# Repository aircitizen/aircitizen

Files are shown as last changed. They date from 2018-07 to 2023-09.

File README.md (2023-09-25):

# AirCitizen

## Air quality measured by citizens

This is the main repo of the [aircitizen](http://www.aircitizen.org) project. The aircitizen project is a citizen science project about air quality.

aircitizen station for CN2 workshops

We develop air quality measurement stations at [Fablab Sorbonne](https://fablab.sorbonne-universite.fr/) in Paris, France and organize participatory workshops (construction of the stations, measurements in a particular neighborhood, data visualization and discussion, ...) with citizens.

## Development

The project is currently under active development. Feel free to contact us if you want to join !

## License



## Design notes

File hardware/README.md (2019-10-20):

<!---just a comment --->

This is the hardware page of the [AirCitizen](http://www.aircitizen.org) project. 

#  Mobile station

We developped this station for the Cité des sciences et de l'industrie and the turfu workshops.

1. arduino mega board
2. battery
3. grove mega shield
4. grove GPS
5. grove temperature and humidity sensor (DHT22)
6. PM sensor Plantower PMS3003 (non grove) with 4-pin adaptor and grove cable
7. I2C OLED display
8. uSD card reader/writer (non grove) with 8Go SD card

<p align="center">
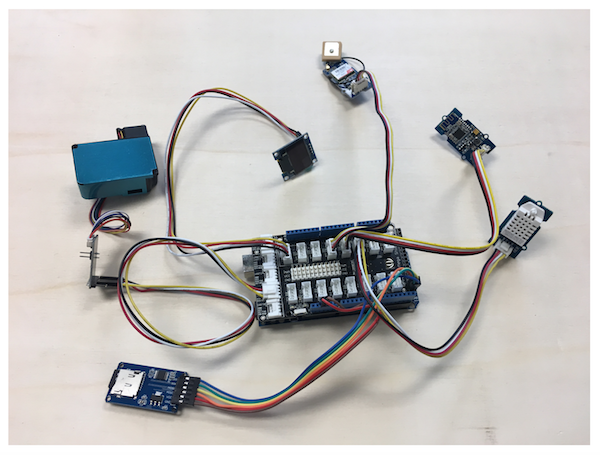
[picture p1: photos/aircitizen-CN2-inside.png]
	
</p>

The station can be assembled by connecting the various components to the shield using grove cable. The SD reader/writer is the exception. It uses the SPI protocol to communicate with the MEGA and must be connected to the Arduino using jumper cables.

# Fixed station (requires power supply and wifi)

We adapted the [Luftdaten](https://luftdaten.info/) to include a noise sensor for a deployment in the north of Paris. 

<p align="center">
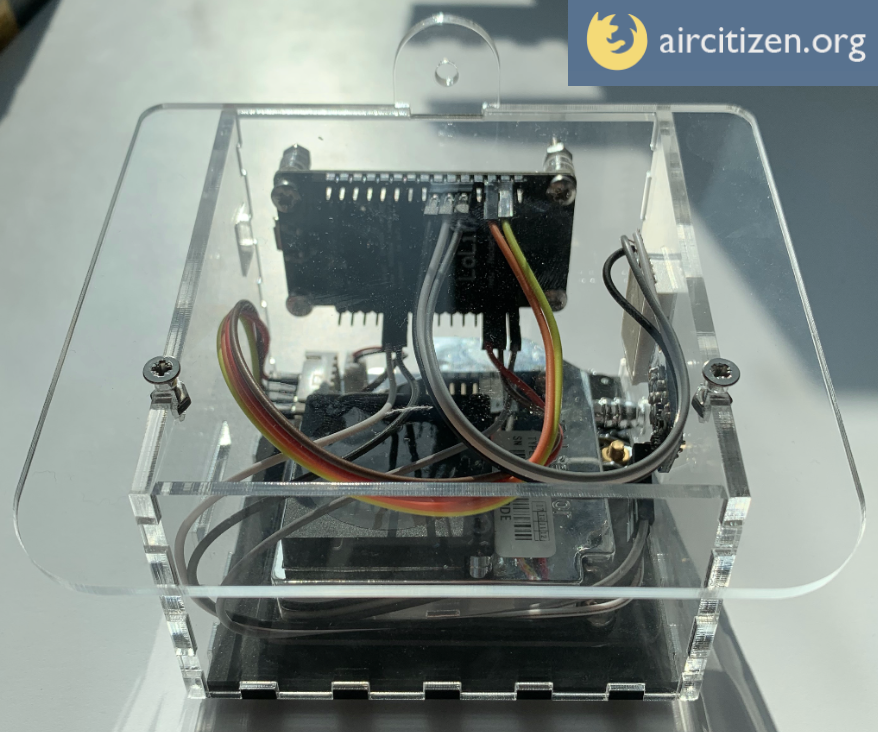
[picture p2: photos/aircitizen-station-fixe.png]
	
</p>

## Bill of Materials
### fixed station rev 1

Component Refs | Type            | Value      | Package | Qty | Supplier #
-------------- | --------------- | ---------- | ------- | :-: | ------------
MCU            | NodeMCU         | -          | -    |  1  | [Amazon](https://www.amazon.fr/ESP8266-nodeMCU/s?k=ESP8266+nodeMCU)
SDS011         | SDS011 dust sensor | -       | -    |  1  | -

</br></br>

To be completed.

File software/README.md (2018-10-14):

## Software 

This is the software page of the [AirCitizen](http://www.aircitizen.org) project. You will find here the firmwares and the libraries used in our various air monitoring stations. Install the libraries in your Arduino IDE (Sketch > Include Library > Add .ZIP library ...), select the board and the port then upload the firmware.

The CN2 and turfu stations are based on Arduino MEGA boards. We provide also test sketches to test the different components (sensors, SD, display, GPS, etc.) independently.

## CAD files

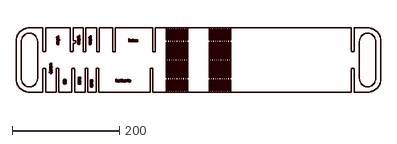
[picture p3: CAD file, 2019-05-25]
hardware/plaque-souple/plaque_lotus_flex.dxf
680.0 x 120.0

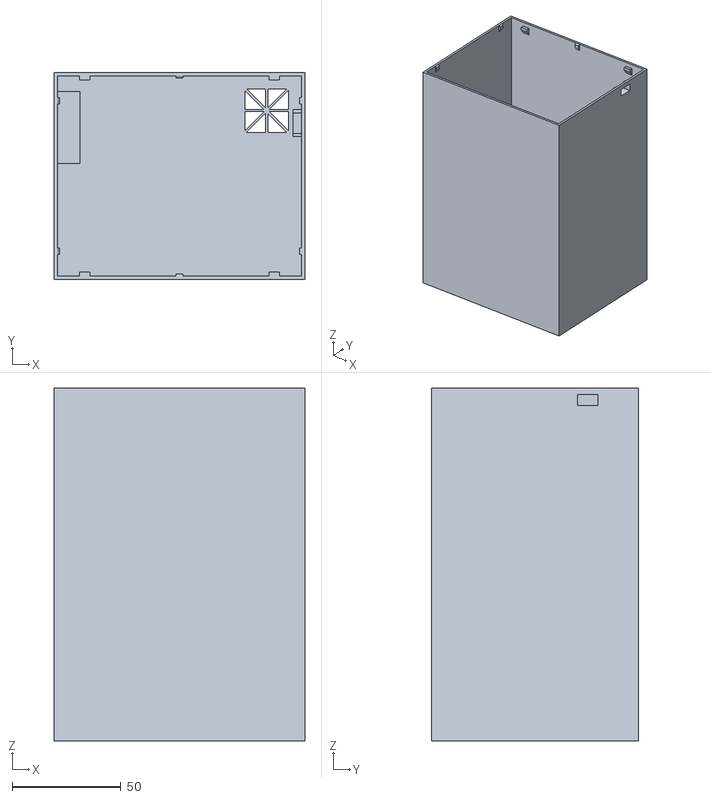
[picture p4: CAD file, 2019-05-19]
hardware/turfu-prototype/couvercle.stl
115.0 x 95.0 x 162.0

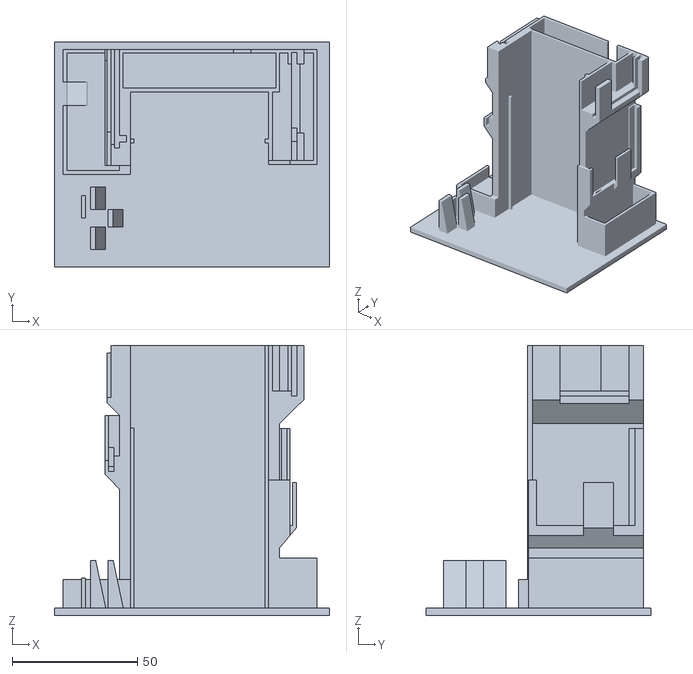
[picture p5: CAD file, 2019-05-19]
hardware/turfu-prototype/boitier_v3.stl
110.0 x 90.0 x 108.0

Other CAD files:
hardware/plaque-souple/plaque_lotus_flex.skp
hardware/turfu-prototype/boitier.skp

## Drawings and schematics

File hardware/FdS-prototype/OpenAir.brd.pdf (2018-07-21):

## OpenAir PMCLab

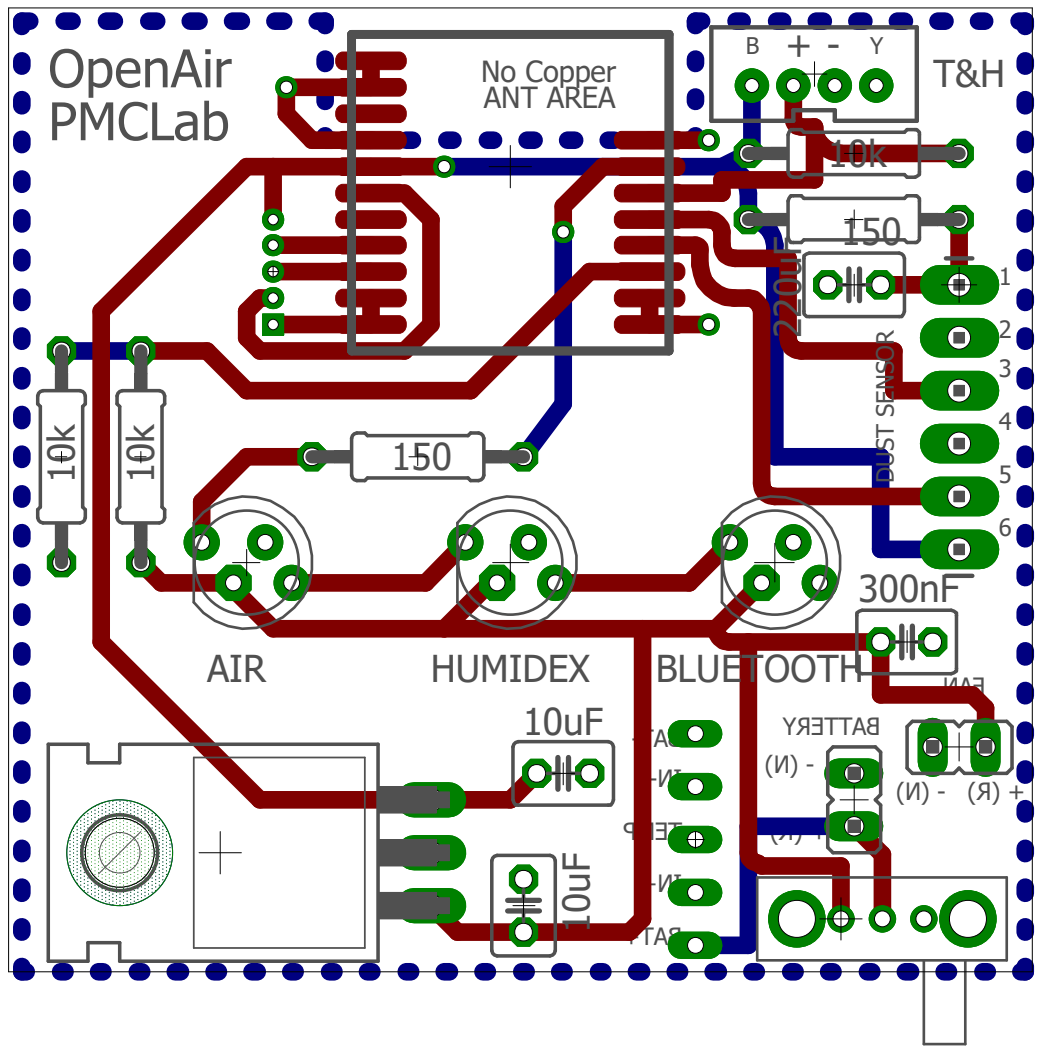
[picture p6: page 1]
300nF DUST SENSOR; AIR; HUMIDEX; BLUETOOTH; ANT AREA; No Copper

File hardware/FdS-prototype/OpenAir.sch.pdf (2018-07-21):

# DHT22LEDS

A

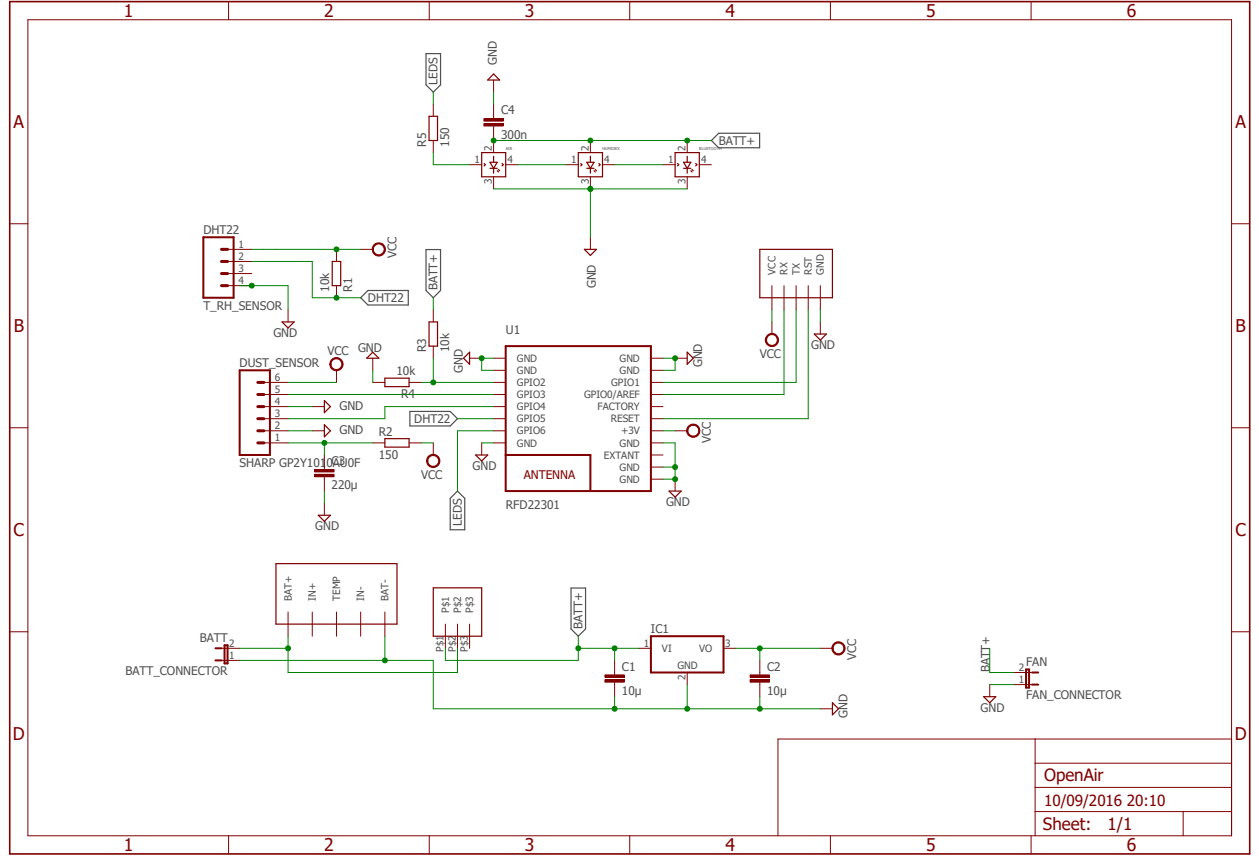
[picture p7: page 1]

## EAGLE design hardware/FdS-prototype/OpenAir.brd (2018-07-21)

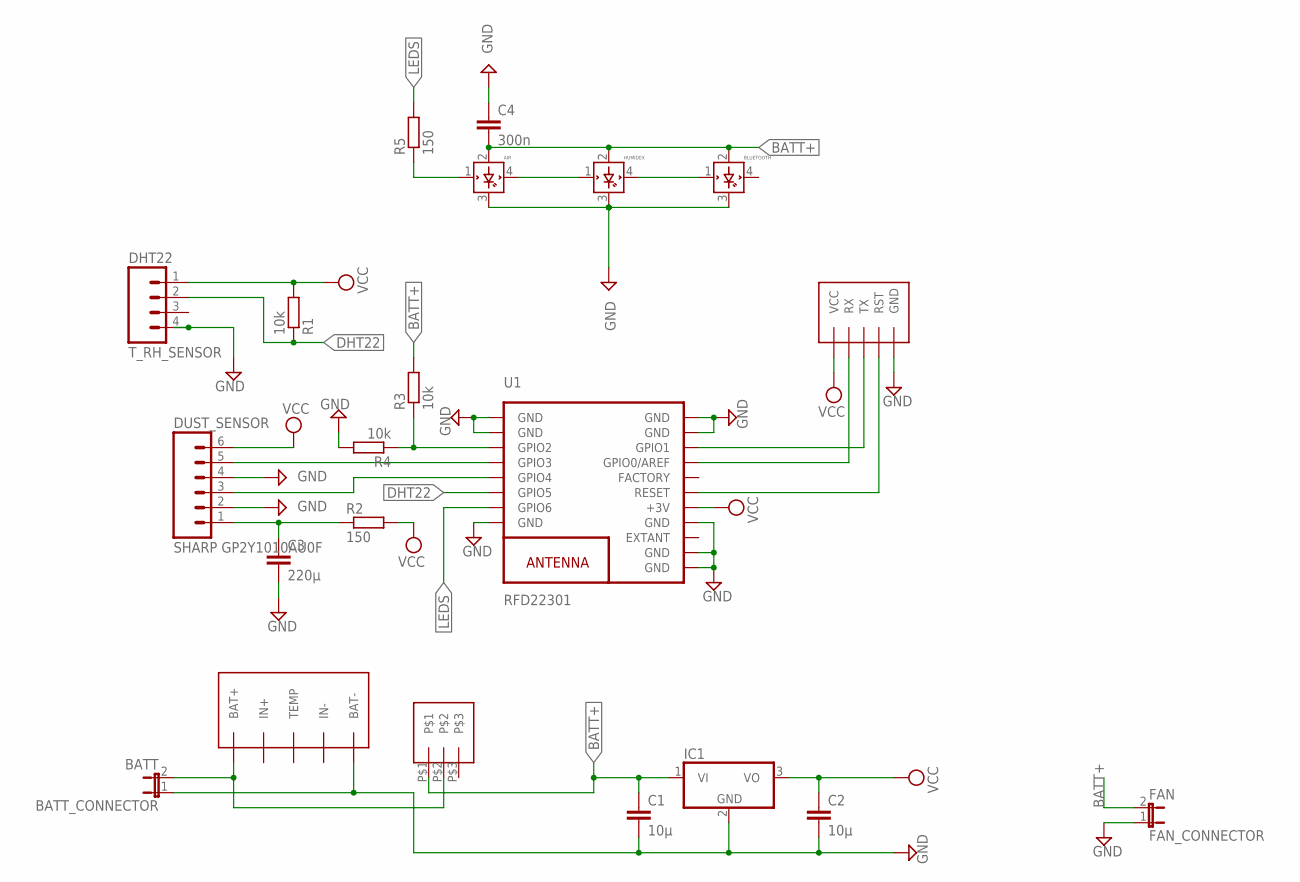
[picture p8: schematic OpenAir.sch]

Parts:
AIR: WS2812BRGB; LED5MMRGB
BATT_CONNECTOR: BATT; JP1
BLUETOOTH: WS2812BRGB; LED5MMRGB
C1, C2: 10µ; C025-030X050
C3: 220µ; C025-030X050
C4: 300n; C025-030X050
DUST_SENSOR: SHARP GP2Y1010AU0F; 1X06_LONGPADS
FAN_CONNECTOR: FAN; JP1
HUMIDEX: WS2812BRGB; LED5MMRGB
IC1: 78T; TO220H
R1, R3, R4: 10k; 0207/10
R2, R5: 150; 0207/10
T_RH_SENSOR: DHT22; JST-4-PTH-VERT
U1: RFD22301
U$1: IC_PROG
U$4: BATT_CHARG
U$5: SPSTCUSTOM

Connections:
BATT+: AIR.2 (VDD), BLUETOOTH.2 (VDD), C1.1, C4.2, FAN_CONNECTOR.2, HUMIDEX.2 (VDD), IC1.1 (VI), R3.2, U$5.P$1
DHT22: R1.1, T_RH_SENSOR.2, U1.6 (GPIO5)
GND: AIR.3 (GND), BATT_CONNECTOR.1, BLUETOOTH.3 (GND), C1.2, C2.2, C3.2, C4.1, DUST_SENSOR.2, DUST_SENSOR.4, FAN_CONNECTOR.1, HUMIDEX.3 (GND), IC1.2 (GND), R4.2, T_RH_SENSOR.4, U1.1 (GND), U1.2 (GND), U1.8 (GND), U1.9 (GND), U1.10 (GND), U1.12 (GND), U1.18 (GND), U1.19 (GND), U$1.GND, U$4.BAT-
LEDS: R5.2, U1.7 (GPIO6)
unnamed: AIR.4 (DOUT), HUMIDEX.1 (DIN)
unnamed: U1.14 (RESET), U$1.RST
unnamed: BLUETOOTH.1 (DIN), HUMIDEX.4 (DOUT)
unnamed: U1.16 (GPIO0/AREF), U$1.RX
unnamed: U1.17 (GPIO1), U$1.TX
unnamed: DUST_SENSOR.5, U1.4 (GPIO3)
unnamed: DUST_SENSOR.3, U1.5 (GPIO4)
unnamed: C3.1, DUST_SENSOR.1, R2.1
unnamed: R3.1, R4.1, U1.3 (GPIO2)
unnamed: BATT_CONNECTOR.2, U$4.BAT+, U$5.P$2
unnamed: AIR.1 (DIN), R5.1
VCC: C2.1, DUST_SENSOR.6, IC1.3 (VO), R1.2, R2.2, T_RH_SENSOR.1, U1.13 (+3V), U$1.VCC

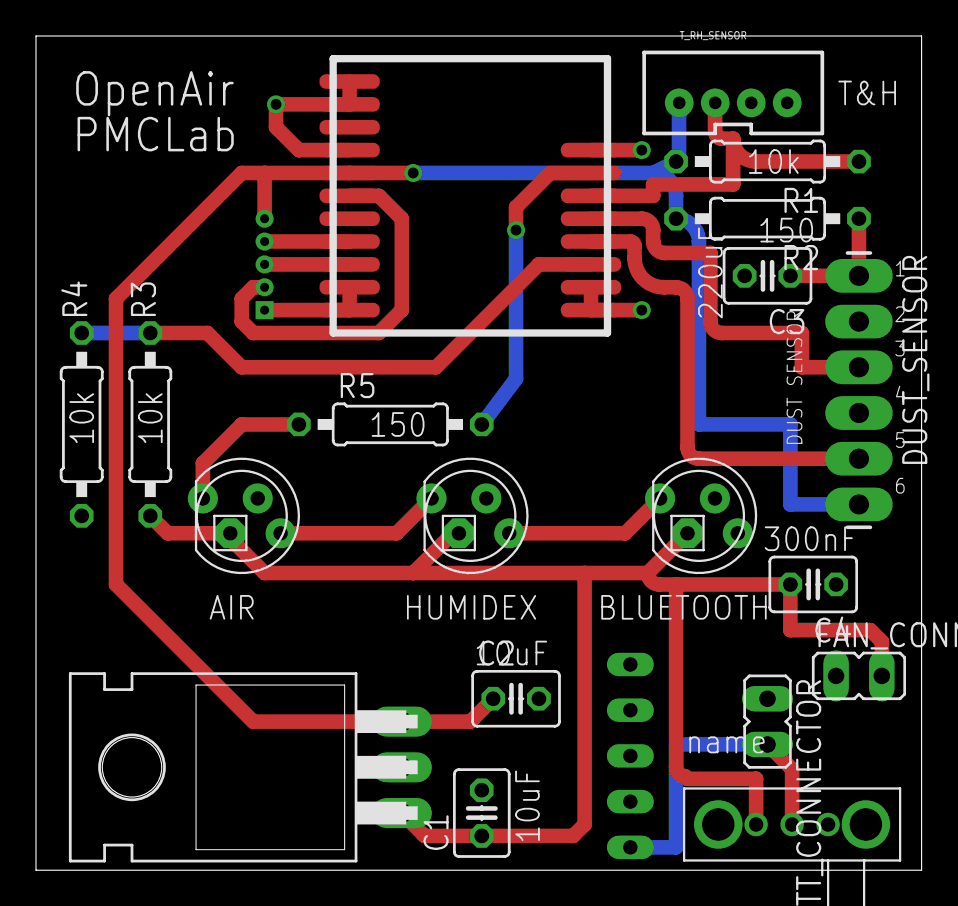
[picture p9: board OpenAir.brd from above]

Board: 2 copper layers, 49.2 x 46.3 mm, 21 parts (0 on the bottom side), 16 nets.

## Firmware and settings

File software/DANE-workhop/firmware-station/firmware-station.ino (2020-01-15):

// Aircitizen - station base Lotus
//
// Authors: Bao Lam Le & Vincent Dupuis
// License CC BY-NC
//
// DHT22 : D7
// GPS : D2
// PMS : D6
// OLED : I2C
// Multichanel gas sensor I2C !!!! CHECK I2C ADRESS! 

// revision
// change pb time BaoLam
// change DHT lib
// add particle numbers for PMS5003

// filename
const char Filename[] = "AirCitizen_5.csv";

// libraries
// GPS
#include <TinyGPS++.h>
#include <SoftwareSerial.h>

// DHT Temp & Hum sensor
#include "DHT.h"

// multichannel gas
#include "MutichannelGasSensor.h"


// OLED I2C display
#include <Wire.h>
#include "SeeedOLED.h"
#include <avr/pgmspace.h>

// SD card 
#include <SPI.h>
#include <SdFat.h>

//Variables
int chk;

//#define debuggEnabled

dht DHT;
#define DHT22_PIN 7

#define RXPin 2      // 
#define TXPin 3      
#define GPSBaud  9600

/*Indicator*/
int INDIC = 0;


/*PMS5003*/
#define LENG 31   //0x42 + 31 bytes equal to 32 bytes
unsigned char buf[LENG];

/*Sensor*/
float lastTemperature = 0;
float lastHumidity = 0;
float lastPM1 = 0;
float lastPM25 = 0;
float lastPM10 = 0;
float lastCO = 0;
float lastNO2 = 0;
// particle numbers
int lastN_03 = 0;
int lastN_05 = 0;
int lastN_1 = 0;
int lastN_25 = 0;
int lastN_5 = 0;
int lastN_10 = 10;


/* Pour l'utilisation de U8glib*/
const uint8_t lineSpacing = 2;
const uint8_t XStartPosition = 0;
const uint8_t YStartPosition = 0;

/* GPS_valid */
bool GPS_valid = false;
bool GPS_GOTDATA = true;
double GPS_longitude = 0;
double GPS_latitude = 0;
/* SD file */
SdFat sd;
SdFile myFile;
// SD card chip select pin.
const uint8_t SD_CS_PIN = 4;
boolean csvInit = false;
  /* Time and date prefix */
#define dateBuf_length        11
static char dateBuf[dateBuf_length] = {'0','0','/','0','0','/','2','0','1','6','\0'};

#define timeBuf_length        9
static char timeBuf[timeBuf_length] = {'0','0',':','0','0',':','0','0','\0'};

//uint8_t bits[5];  // buffer to receive data of dht22

#define TIMEOUT 10000

static const char* DATA_UPDATE[18]={
  "GPS",
  "UTC Date",
  "UTC Time", 
  "Latitude",
  "Longitude",
  "Temp",
  "Humid",
  "PM1",
  "PM2.5",
  "PM10",
  "CO",
  "NO2",
  "N_0.3",
  "N_0.5",
  "N_1.0",
  "N_2.5",
  "N_5.0",
  "N_10.0"
};

static const char* UNITS[18]={
  "",
  "",
  "",
  "",
  "",
  "C",
  "%",
  "ug/m3",
  "ug/m3",
  "ug/m3",
  "ppm",
  "ppb",
  "",
  "",
  "",
  "",
  "",
  ""
};

// The TinyGPS++ object
TinyGPSPlus tinyGPS;

// The serial connection to the GPS device
SoftwareSerial ss(RXPin, TXPin);
#define gpsPort ss

// Plantower on sspms
SoftwareSerial sspms(6, 7);


// function draw()

void draw(){

  void *OledData_buf[11] = {dateBuf, timeBuf, &GPS_latitude, &GPS_longitude, &lastTemperature, &lastHumidity, &lastPM1, &lastPM25, &lastPM10, &lastCO, &lastNO2};

  SeeedOled.clearDisplay();          //clear the screen and set start position to top left corner

  SeeedOled.setTextXY(0,0);  
  //SeeedOled.setGrayLevel(15); //Set Grayscale level. Any number between 0 - 15.
  SeeedOled.putString(DATA_UPDATE[0]); SeeedOled.putString(": ");
  if (GPS_valid){
    SeeedOled.putString("o");
  }
  else {
    SeeedOled.putString("x");
  }

  //u8g.print("       ");
  SeeedOled.putString("       ");
  if (INDIC==1) {
    SeeedOled.putString("-");
    }
  else {
    SeeedOled.putString("|");
  }
  // Date and time
  //SeeedOled.setTextXY(1, 0);
  //SeeedOled.putString((char*)OledData_buf[1]);
  //SeeedOled.setTextXY(2, 0);
  //SeeedOled.putString((char*)OledData_buf[2]);
  // RH and Temperature
  //SeeedOled.setTextXY(3, 0);
  //SeeedOled.putString("T=");SeeedOled.putNumber(*((float*)OledData_buf[4])); SeeedOled.putString(" "); SeeedOled.putString(UNITS[5]);  
  //SeeedOled.putString(" ");
  //SeeedOled.putString("RH=");SeeedOled.putNumber(*((float*)OledData_buf[5])); SeeedOled.putString(" "); SeeedOled.putString(UNITS[6]);
  //SeeedOled.putString(" ");
  
 SeeedOled.setTextXY(2,0);
  SeeedOled.putString(DATA_UPDATE[7]); SeeedOled.putString(":   ");  
  SeeedOled.putNumber(*((float*)OledData_buf[6])); SeeedOled.putString(" "); SeeedOled.putString(UNITS[7]);

  SeeedOled.setTextXY(3, 0);
  SeeedOled.putString(DATA_UPDATE[8]); SeeedOled.putString(": ");  
  SeeedOled.putNumber(*((float*)OledData_buf[7])); SeeedOled.putString(" "); SeeedOled.putString(UNITS[8]);

  SeeedOled.setTextXY(4,0);
  SeeedOled.putString(DATA_UPDATE[9]); SeeedOled.putString(":  ");  
  SeeedOled.putNumber(*((float*)OledData_buf[8])); SeeedOled.putString(" "); SeeedOled.putString(UNITS[9]);

  SeeedOled.setTextXY(5,0);
  SeeedOled.putString(DATA_UPDATE[10]); SeeedOled.putString(":  ");  
  SeeedOled.putNumber(*((float*)OledData_buf[9])); SeeedOled.putString(" "); SeeedOled.putString(UNITS[10]);    

  SeeedOled.setTextXY(6,0);
  SeeedOled.putString(DATA_UPDATE[11]); SeeedOled.putString(":  ");  
  SeeedOled.putNumber(*((float*)OledData_buf[10])); SeeedOled.putString(" "); SeeedOled.putString(UNITS[11]);  
}

void setup() {
  Serial.begin(9600);
  // OLED
  Wire.begin();
  SeeedOled.init();             //initialize SEEED OLED display
  SeeedOled.clearDisplay();     //Clear Display.
  SeeedOled.setNormalDisplay(); //Set Normal Display Mode
  //SeeedOled.setVerticalMode();  // Set to vertical mode for displaying text
  
  // GPS
  ss.begin(GPSBaud);
  delay(100);
  //PMS on sspms;
  sspms.begin(9600);
  delay(100);
  ss.listen();
  // DHT
  //dht.begin();
 
  if (!sd.begin(SD_CS_PIN)) {
  #ifdef debuggEnabled
      Serial.println(F("initialization failed!"));
  #endif 
      return;
    }
   
 
  #ifdef debuggEnabled
  Serial.println(F("initialization done."));   
  #endif 
  if (!sd.exists(Filename)) {
    #ifdef debuggEnabled
      Serial.println(F("Creating AirCitizen.csv..."));
    #endif 
    myFile.open(Filename, FILE_WRITE);
    myFile.close();
    delay(1000);
    txHeader();
    
  } else{
    #ifdef debuggEnabled
      Serial.println(F("AirCitizen.csv exists ..."));
    #endif 
  }   

    // CHECK I2C ADDRESS !!! 2 ercicka 1 transp
    gas.begin(0x02);//the default I2C address of the slave is 0x04
    gas.powerOn();
    #ifdef debuggEnabled
      Serial.print("Firmware Version = ");
      Serial.println(gas.getVersion());
    #endif 

}
// ----------------------------------------------------------------------------------------------------------------
void loop() {
  /*
  // picture loop
  u8g.firstPage();  
  do {
    draw();
  } while( u8g.nextPage());   
  */
  ss.listen();
  delay(100);
  // rebuild the picture after some delay
  if(GPS_GOTDATA) {
    feedGPS();
    GPS_GOTDATA = false;
  }
  sckDHT22();
  sspms.listen();
  delay(100);
  sckPMS();
  ss.listen();
  sckGAS();
  txSD();

  if (INDIC==1) {INDIC = 0;}
  else {INDIC = 1;}
  
  draw();  
  smartDelay(1000);
  
}
// ----------------------------------------------------------------------------------------------------------------

static void feedGPS() {
  /*Date et time */
  uint8_t Hour = 12;
  uint8_t Minute = 50;
  uint8_t Second = 33;
  uint16_t Year = 2012;
  uint8_t Month = 5;
  uint8_t Day = 5;
  if (tinyGPS.location.isValid()){
    GPS_valid = true; 
    GPS_longitude = tinyGPS.location.lat();
    GPS_latitude =  tinyGPS.location.lng();
  } else {
    GPS_valid = false; 
  }
  if(tinyGPS.date.isValid()){
    Year = tinyGPS.date.year();
    Month = tinyGPS.date.month();
    Day = tinyGPS.date.day();
    sckDate(Day,Month,Year);
  }
  if (tinyGPS.time.isValid()) {
    Hour = tinyGPS.time.hour();
    Minute = tinyGPS.time.minute();
    Second = tinyGPS.time.second();
    sckTime(Second, Minute, Hour);
  }
  #ifdef debuggEnabled
  Serial.print("feed GPS OK");
  #endif
}

// This custom version of delay() ensures that the tinyGPS object
// is being "fed". From the TinyGPS++ examples.
static void smartDelay(unsigned long ms)
{
  unsigned long start = millis();
  do
  {
    // If data has come in from the GPS module
    while (gpsPort.available())
      if(tinyGPS.encode(gpsPort.read())) {
        GPS_GOTDATA = true; // Send it to the encode function
      }
  // tinyGPS.encode(char) continues to "load" the tinGPS object with new
  // data coming in from the GPS module. As full NMEA strings begin to come in
  // the tinyGPS library will be able to start parsing them for pertinent info
  } while (millis() - start < ms);
}

boolean sckDHT22()
{
  int chk = DHT.read22(DHT22_PIN);
  // READ DATA
  float hum = DHT.humidity;
  float temp = DHT.temperature;
  //float h = dht.readHumidity();
  //float t = dht.readTemperature();
  #ifdef debuggEnabled
    Serial.println("");
    Serial.print("Humidity: "); 
    Serial.print(hum);
    Serial.println(" %");
    Serial.print("Temperature: "); 
    Serial.print(temp);
    Serial.println(" *C");
  #endif
  lastTemperature = temp;
  lastHumidity = hum;

  return true;
}


void sckPMS()
{   
    if(sspms.find(0x42)){    
    sspms.readBytes(buf,LENG);
    if(buf[0] == 0x4d){
      if(checkValue(buf,LENG)){
        lastPM1 = (buf[9]<<8) + buf[10];
        lastPM25 = (buf[11]<<8) + buf[12];
        lastPM10 = (buf[13]<<8) + buf[14];
        lastN_03=(buf[15]<<8) + buf[16];
        lastN_05=(buf[17]<<8) + buf[18];
        lastN_1=(buf[19]<<8) + buf[20];
        lastN_25=(buf[21]<<8) + buf[22];
        lastN_5=(buf[23]<<8) + buf[24];
        lastN_10=(buf[25]<<8) + buf[26];
        //transmitPM01(buf); //count PM1.0 value of the air detector module
        //transmitPM2_5(buf);//count PM2.5 value of the air detector module
        //transmitPM10(buf); //count PM10 value of the air detector module
      }           
    } 
  }
  #ifdef debuggEnabled
        Serial.print("PM1_0: ");  
        Serial.print(lastPM1);
        Serial.println("  ug/m3");            
        Serial.print("PM2_5: ");  
        Serial.print(lastPM25);
        Serial.println("  ug/m3");     
        Serial.print("PM10: ");  
        Serial.print(lastPM10);
        Serial.println("  ug/m3");   
        Serial.println();
  #endif
      
}

void sckGAS()
{   
  lastCO = gas.measure_CO();
  #ifdef debuggEnabled
    Serial.print("The concentration of CO is ");
    if(lastCO>=0) Serial.print(lastCO);
    else Serial.print("invalid");
    Serial.println(" ppm");
  #endif 
  lastNO2 = 1000.0*gas.measure_NO2();
  #ifdef debuggEnabled
    Serial.print("The concentration of NO2 is ");
    if(lastNO2>=0) Serial.print(lastNO2);
    else Serial.print("invalid");
    Serial.println(" ppm");
  #endif 
}

void txSD() {
  #ifdef debuggEnabled
  Serial.println("*** txSD ***");
  #endif
  
  // if the file opened okay, write to it:
  
  if (myFile.open(Filename, FILE_WRITE)) {
  #ifdef debuggEnabled
      Serial.println(F("Writing...")); 
  #endif 
  myFile.print(GPS_valid);
  myFile.print(",");
  myFile.print(dateBuf);
  myFile.print(",");  
  myFile.print(timeBuf);
  myFile.print(",");
  myFile.print(GPS_longitude,7);
  myFile.print(",");
  myFile.print(GPS_latitude,7);
  myFile.print(",");
  myFile.print(lastTemperature);
  myFile.print(",");
  myFile.print(lastHumidity);
  myFile.print(",");
  myFile.print(lastPM1);
  myFile.print(",");
  myFile.print(lastPM25);
  myFile.print(",");
  myFile.print(lastPM10);
  myFile.print(",");
  myFile.print(lastCO);
  myFile.print(",");
  myFile.print(lastNO2);
  myFile.print(",");
  myFile.print(lastN_03);
  myFile.print(",");
  myFile.print(lastN_05);
  myFile.print(",");
  myFile.print(lastN_1);
  myFile.print(",");
  myFile.print(lastN_25);
  myFile.print(",");
  myFile.print(lastN_5);
  myFile.print(",");
  myFile.print(lastN_10);
  myFile.println();
  
  // close the file:
  myFile.close();

    
//#ifdef debuggEnabled
  Serial.print(GPS_valid);
  Serial.print(",");
  Serial.print(dateBuf);
  Serial.print(",");  
  Serial.print(timeBuf);
  Serial.print(",");
  Serial.print(GPS_longitude,7);
  Serial.print(",");
  Serial.print(GPS_latitude,7);
  Serial.print(",");
  Serial.print(lastTemperature);
  Serial.print(",");
  Serial.print(lastHumidity);
  Serial.print(",");
  Serial.print(lastPM1);
  Serial.print(",");
  Serial.print(lastPM25);
  Serial.print(",");
  Serial.print(lastPM10);
  Serial.print(",");
  Serial.print(lastCO);
  Serial.print(",");
  Serial.print(lastNO2);
  Serial.print(",");
  Serial.print(lastN_03);
  Serial.print(",");
  Serial.print(lastN_05);
  Serial.print(",");
  Serial.print(lastN_1);
  Serial.print(",");
  Serial.print(lastN_25);
  Serial.print(",");
  Serial.print(lastN_5);
  Serial.print(",");
  Serial.print(lastN_10);
  Serial.println();
  Serial.println(F("Closing...")); 
//#endif 
  }
}

void txHeader() { 
  #ifdef debuggEnabled
  Serial.println("*** txHeader ***");
  #endif
  // if the file opened okay, write to it:
  if (myFile.open(Filename, FILE_WRITE)) {
  #ifdef debuggEnabled
      Serial.println(F("Writing...")); 
  #endif 
    for (uint8_t i=0; i<17; i++)
    {
      myFile.print(DATA_UPDATE[i]);
      myFile.print(", ");
    }
    myFile.print(DATA_UPDATE[18]);
    myFile.println();
    // close the file:
    myFile.close();
    #ifdef debuggEnabled
        Serial.println(F("Closing...")); 
    #endif 
  }
}

char* sckDate(uint8_t dayin, uint8_t monthin, uint16_t yearin) {
  char zero = '0';
  dateBuf[0] = (dayin / 10) + zero;
  dateBuf[1] = (dayin % 10) + zero;
  dateBuf[3] = (monthin / 10) + zero;
  dateBuf[4] = (monthin % 10) + zero;
  dateBuf[8] = (yearin % 100)/10 + zero;
  dateBuf[9] = (yearin % 10) + zero;
  return dateBuf;
}

char* sckTime(uint8_t secondein, uint8_t minutein, uint8_t hourin) {
  char zero = '0';
  timeBuf[0] = (hourin / 10) + zero;
  timeBuf[1] = (hourin % 10) + zero;
  timeBuf[3] = (minutein / 10) + zero;
  timeBuf[4] = (minutein % 10) + zero;
  timeBuf[6] = (secondein / 10) + zero;
  timeBuf[7] = (secondein % 10) + zero;
  return timeBuf;
}

// PMS functions
char checkValue(unsigned char *thebuf, char leng)
{  
  char receiveflag=0;
  int receiveSum=0;

  for(int i=0; i<(leng-2); i++){
  receiveSum=receiveSum+thebuf[i];
  }
  receiveSum=receiveSum + 0x42;
 
  if(receiveSum == ((thebuf[leng-2]<<8)+thebuf[leng-1]))  //check the serial data 
  {
    receiveSum = 0;
    receiveflag = 1;
  }
  return receiveflag;
}

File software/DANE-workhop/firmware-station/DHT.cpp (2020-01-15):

//
//    FILE: dht.cpp
//  AUTHOR: Rob Tillaart
// VERSION: 0.1.29
// PURPOSE: DHT Temperature & Humidity Sensor library for Arduino
//     URL: http://arduino.cc/playground/Main/DHTLib
//
// HISTORY:
// 0.1.29 2018-09-02 fix negative temperature DHT12 - issue #111
// 0.1.28 2018-04-03 refactor
// 0.1.27 2018-03-26 added _disableIRQ flag
// 0.1.26 2017-12-12 explicit support for AM23XX series and DHT12
// 0.1.25 2017-09-20 FIX https://github.com/RobTillaart/Arduino/issues/80
// 0.1.24 2017-07-27 FIX https://github.com/RobTillaart/Arduino/issues/33  double -> float
// 0.1.23 2017-07-24 FIX https://github.com/RobTillaart/Arduino/issues/31
// 0.1.22 undo delayMicroseconds() for wakeups larger than 8
// 0.1.21 replace delay with delayMicroseconds() + small fix
// 0.1.20 Reduce footprint by using uint8_t as error codes. (thanks to chaveiro)
// 0.1.19 masking error for DHT11 - FIXED (thanks Richard for noticing)
// 0.1.18 version 1.16/17 broke the DHT11 - FIXED
// 0.1.17 replaced micros() with adaptive loopcount
//        removed DHTLIB_INVALID_VALUE
//        added  DHTLIB_ERROR_CONNECT
//        added  DHTLIB_ERROR_ACK_L  DHTLIB_ERROR_ACK_H
// 0.1.16 masking unused bits (less errors); refactored bits[]
// 0.1.15 reduced # micros calls 2->1 in inner loop.
// 0.1.14 replace digital read with faster (~3x) code => more robust low MHz machines.
//
// 0.1.13 fix negative temperature
// 0.1.12 support DHT33 and DHT44 initial version
// 0.1.11 renamed DHTLIB_TIMEOUT
// 0.1.10 optimized faster WAKEUP + TIMEOUT
// 0.1.09 optimize size: timeout check + use of mask
// 0.1.08 added formula for timeout based upon clockspeed
// 0.1.07 added support for DHT21
// 0.1.06 minimize footprint (2012-12-27)
// 0.1.05 fixed negative temperature bug (thanks to Roseman)
// 0.1.04 improved readability of code using DHTLIB_OK in code
// 0.1.03 added error values for temp and humidity when read failed
// 0.1.02 added error codes
// 0.1.01 added support for Arduino 1.0, fixed typos (31/12/2011)
// 0.1.00 by Rob Tillaart (01/04/2011)
//
// inspired by DHT11 library
//
// Released to the public domain
//

#include "dht.h"

/////////////////////////////////////////////////////
//
// PUBLIC
//

int8_t dht::read11(uint8_t pin)
{
    // READ VALUES
    if (_disableIRQ) noInterrupts();
    int8_t result = _readSensor(pin, DHTLIB_DHT11_WAKEUP, DHTLIB_DHT11_LEADING_ZEROS);
    if (_disableIRQ) interrupts();

    // these bits are always zero, masking them reduces errors.
    bits[0] &= 0x7F;
    bits[2] &= 0x7F;

    // CONVERT AND STORE
    humidity    = bits[0];  // bits[1] == 0;
    temperature = bits[2];  // bits[3] == 0;

    // TEST CHECKSUM
    uint8_t sum = bits[0] + bits[1] + bits[2] + bits[3];
    if (bits[4] != sum)
    {
        return DHTLIB_ERROR_CHECKSUM;
    }
    return result;
}

int8_t dht::read12(uint8_t pin)
{
    // READ VALUES
    if (_disableIRQ) noInterrupts();
    int8_t result = _readSensor(pin, DHTLIB_DHT11_WAKEUP, DHTLIB_DHT11_LEADING_ZEROS);
    if (_disableIRQ) interrupts();

    // CONVERT AND STORE
    humidity = bits[0] + bits[1] * 0.1;
    temperature = bits[2] + (bits[3] & 0x7F) * 0.1;
    if (bits[3] & 0x80)  // negative temperature
    {
        temperature = -temperature;
    }

    // TEST CHECKSUM
    uint8_t sum = bits[0] + bits[1] + bits[2] + bits[3];
    if (bits[4] != sum)
    {
        return DHTLIB_ERROR_CHECKSUM;
    }
    return result;
}

int8_t dht::read(uint8_t pin)
{
    // READ VALUES
    if (_disableIRQ) noInterrupts();
    int8_t result = _readSensor(pin, DHTLIB_DHT_WAKEUP, DHTLIB_DHT_LEADING_ZEROS);
    if (_disableIRQ) interrupts();

    // these bits are always zero, masking them reduces errors.
    bits[0] &= 0x03;
    bits[2] &= 0x83;

    // CONVERT AND STORE
    humidity = (bits[0]*256 + bits[1]) * 0.1;
    temperature = ((bits[2] & 0x7F)*256 + bits[3]) * 0.1;
    if (bits[2] & 0x80)  // negative temperature
    {
        temperature = -temperature;
    }

    // TEST CHECKSUM
    uint8_t sum = bits[0] + bits[1] + bits[2] + bits[3];
    if (bits[4] != sum)
    {
        return DHTLIB_ERROR_CHECKSUM;
    }
    return result;
}

/////////////////////////////////////////////////////
//
// PRIVATE
//

int8_t dht::_readSensor(uint8_t pin, uint8_t wakeupDelay, uint8_t leadingZeroBits)
{
    // INIT BUFFERVAR TO RECEIVE DATA
    uint8_t mask = 128;
    uint8_t idx = 0;

    uint8_t data = 0;
    uint8_t state = LOW;
    uint8_t pstate = LOW;
    uint16_t zeroLoop = DHTLIB_TIMEOUT;
    uint16_t delta = 0;

    leadingZeroBits = 40 - leadingZeroBits; // reverse counting...

    // replace digitalRead() with Direct Port Reads.
    // reduces footprint ~100 bytes => portability issue?
    // direct port read is about 3x faster
    uint8_t bit = digitalPinToBitMask(pin);
    uint8_t port = digitalPinToPort(pin);
    volatile uint8_t *PIR = portInputRegister(port);

    // REQUEST SAMPLE
    pinMode(pin, OUTPUT);
    digitalWrite(pin, LOW); // T-be
    if (wakeupDelay > 8) delay(wakeupDelay);
    else delayMicroseconds(wakeupDelay * 1000UL);
    // digitalWrite(pin, HIGH); // T-go
    pinMode(pin, INPUT);

    uint16_t loopCount = DHTLIB_TIMEOUT * 2;  // 200uSec max
    // while(digitalRead(pin) == HIGH)
    while ((*PIR & bit) != LOW )
    {
        if (--loopCount == 0) 
        {
          return DHTLIB_ERROR_CONNECT;
        }
    }

    // GET ACKNOWLEDGE or TIMEOUT
    loopCount = DHTLIB_TIMEOUT;
    // while(digitalRead(pin) == LOW)
    while ((*PIR & bit) == LOW )  // T-rel
    {
        if (--loopCount == 0) 
        {
          return DHTLIB_ERROR_ACK_L;
        }
    }

    loopCount = DHTLIB_TIMEOUT;
    // while(digitalRead(pin) == HIGH)
    while ((*PIR & bit) != LOW )  // T-reh
    {
        if (--loopCount == 0)
        {
          return DHTLIB_ERROR_ACK_H;
        }
    }

    loopCount = DHTLIB_TIMEOUT;

    // READ THE OUTPUT - 40 BITS => 5 BYTES
    for (uint8_t i = 40; i != 0; )
    {
        // WAIT FOR FALLING EDGE
        state = (*PIR & bit);
        if (state == LOW && pstate != LOW)
        {
            if (i > leadingZeroBits) // DHT22 first 6 bits are all zero !!   DHT11 only 1
            {
                zeroLoop = min(zeroLoop, loopCount);
                delta = (DHTLIB_TIMEOUT - zeroLoop)/4;
            }
            else if ( loopCount <= (zeroLoop - delta) ) // long -> one
            {
                data |= mask;
            }
            mask >>= 1;
            if (mask == 0)   // next byte
            {
                mask = 128;
                bits[idx] = data;
                idx++;
                data = 0;
            }
            // next bit
            --i;

            // reset timeout flag
            loopCount = DHTLIB_TIMEOUT;
        }
        pstate = state;
        // Check timeout
        if (--loopCount == 0)
        {
          return DHTLIB_ERROR_TIMEOUT;
        }

    }
    // pinMode(pin, OUTPUT);
    // digitalWrite(pin, HIGH);
    return DHTLIB_OK;
}
//
// END OF FILE
//

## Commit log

2018-07-21 added Eagle files
    [OpenAir.brd, OpenAir.sch]
2018-10-14 Add turfu prototype
2019-04-17 boitier_v3
    plan pour un boitier fabriqué par impression 3D (dépôt de fil, PLA)
    [boitier.skp, boitier_v3.stl, couvercle.stl]
2019-05-25 plans et photos
    Nouveau concept de "boitier" pour la version avec carte Lotus, fonctionne aussi avec un Arduino MEGA + shield grove en occupant l'emplacement vide qui peut servir à ranger les cables.
    [plaque_lotus_flex.dxf, plaque_lotus_flex.skp]

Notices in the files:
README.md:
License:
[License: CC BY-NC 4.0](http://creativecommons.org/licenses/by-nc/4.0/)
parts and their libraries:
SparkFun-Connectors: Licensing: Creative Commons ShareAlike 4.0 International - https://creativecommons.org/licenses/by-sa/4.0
